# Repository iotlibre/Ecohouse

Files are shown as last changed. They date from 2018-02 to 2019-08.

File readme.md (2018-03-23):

# EcoHouse

Este kit de medida está pensado para tomar las medidas de consumo eléctrico de una vivienda o de un edificio con consumos inferiores a 10 KW. El sistema permite diferenciar varias zonas.

EcoHouse se puede instalar en el cuadro eléctrico principal o en cualquier otra parte  que nos permita tomar datos del consumo mediante pinzas (transformadores de intensidad). 

En el un edificio podemos tener tantos dispositivos como sean necesarios y el servidor EcoEficiencia los integrará en la misma instalación sin necesidad de configuraciones adicionales o cambios en el Firmware.

La comunicación se hace mediante Wifi por lo que no es necesario el cableado de datos al equipo solamente es necesario que esté dentro de la cobertura de la red WIFI del edificio. 

Para su uso no son necesarios conocimientos de informática aunque todos los desarrollos y el hardware están hechos bajo licencias libres lo que permite la modificación y mejora de las funcionalidades.

## Listado con las principales características
Las principales características de EcoBuilding son:
- 6 entradas para sensores de corriente con salida estandar de 50 mA o 1 Voltio
- Comunicación a Internet por WIFI local
- Configurable vía Web
- Display para mostrar el consumo instantáneo
- Alimentación a 220 voltios de corriente alterna
- Montaje en carril din
- Es posible configurar dos entradas analógicas adicionales pero en este caso el display permanecerá inoperativo
- La PCB integra un Arduino nano  con el ESP8266 12E
- Compatible con el [servidor de Open Energy Monitor](https://emoncms.org/)

## Montaje
El listado de componentes que has debido recibir es el siguientes:

- 1 PCB con los componentes de superficie ya montados
- 1 Carcasa para carril DIN
- 1 Tapa superior carcasa con display LCD 1602 y adaptador IIC/I2C
- 1 PCB Mesh building
- 1 Fuente de alimentación a 12 voltios
- 1 Arduino Nano
- 1 Integrado ESP8266 12E con el firmware mesh_building incluido
- 1 Convertidor DC-DC Step Down ajustable (salida 7,5V)
- 1 Regulador de tensión LM 1117
- 2 Conectores macho -hembra de 2.0mm para el ESP
- 2 Conectores macho hembra de 2.54mm para Arduino
- 2 Conectores macho hembra de 2.54mm para al display
- 9 Terminales de tornillo para PCB
- 2 Resistencias 10k 
- 3 Condensador 22uF
- 1 Condensador de 100nF
- 1 Diodo 1N4007

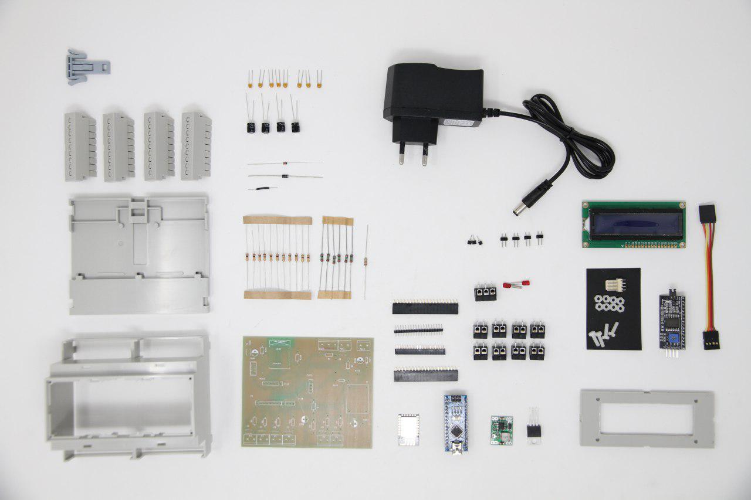
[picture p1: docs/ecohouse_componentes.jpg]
ecohouse_componentes


## Montaje
Partiendo de la PCB con los componentes de superficie soldar los componentes de menor a mayor tamaño por este orden:
- Resistencias
- Diodos
- Convertidor DC-DC Step Down ajustable (salida 7,5V)
- Conectores macho hembra de 2.0mm para el ESP
- Conectores macho hembra de 2.54mm para Arduino
- Conectores macho hembra de 2.54mm para al display
- Terminales de tornillo para PCB
- Condensador 22uF
- Condensador de 100nF
- Regulador de tensión LM 1117
 
Una vez esta completa la PCB insertar los integrados en sus posiciones
- Integrado ESP8266 12E
- Arduino Nano

Mirar la imagen para colocar los integrados de forma correcta, de otra maner no funcionarán y pueden sufrir daños
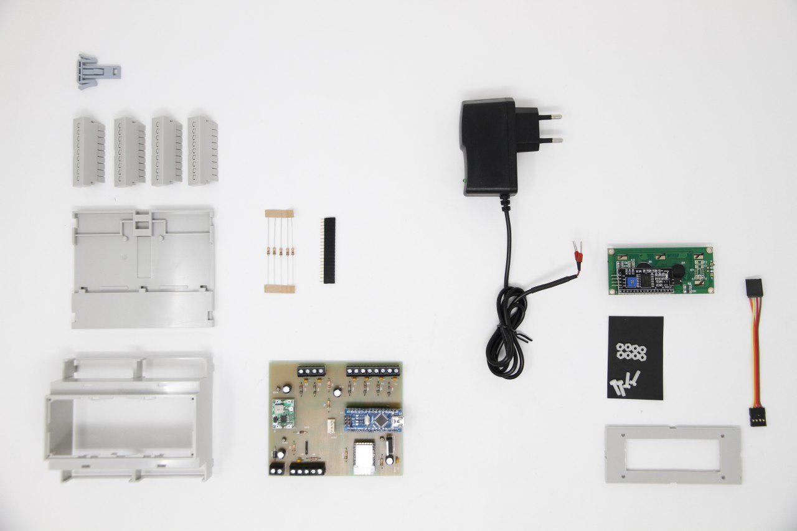
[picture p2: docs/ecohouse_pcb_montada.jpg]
ecohouse pcb montada


Por último conectar la tapa superior con el display a la PCB y montar la carcasa.

## Puesta a punto
La puesta a punto de libre_building consta de dos partes:
- El ajuste del voltaje de trabajo
- La configuración en la instalación

### El ajuste del voltaje de trabajo
El ajuste del voltaje de trabajo se hace para adaptar cualquier alimentación al voltaje de trabajo de EcoHouse que es 7,5 voltios.

La fuente de alimentación suministrada es de 12 voltios aunque el dispositivo funciona correctamente siempre que el voltaje de trabajo quede configurado entre 7 y 9 voltios.

Una vez conectada la  fuente de alimentación medir el voltaje en el punto (W103), situado al lado de  el Convertidor DC-DC (U1), y ajustarlo a 7,5 voltios con el potenciómetro que incorpora el convertidor. 

### La configuración en la instalación
En este punto se definen los parámetros del servidor de destino y la wifi local a la que va a estar conectado el dispositivo. Con este fin, la primera vez que se ponga en servicio el ESP y siempre que no encuentre la WIFI configurada, el ESP 8266 12E creará su propio punto de acceso, su propia red WIFI . Conectandose a cualquier dirección a través de este punto de acceso nos aparecerá la página de configuración del ESP. Tengase en cuenta que una  vez configurado el ESP y conectado a una red WIFI el router le asignará una única dirección IP a la que será necesario acceder para cambiar la configuración.

En caso de que se quiera actualizar el firmware del ESP a la última versión, este se puede encontrar en: [ecohouse-emonESP ](https://github.com/iotlibre/Ecohouse/tree/master/EmonESP)

### El firmware de Arduino
El firmware que que esta cargado por defecto en el arduino nano funciona correctamente sin embargo si quiere cambiar la configuración puedes encontrar la última actualización del firmware en este repositorio:[ecohouse-nano ](https://github.com/iotlibre/Ecohouse/tree/master/ecohouse-arduino_1)

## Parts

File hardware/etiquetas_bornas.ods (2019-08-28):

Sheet: Sheet1
CA | GND |  |  |  |  |  |  | 12V | GND
5V | 18B | GND
I1 | GND | I2 | GND | PR | GND
24 | GND | +30 | -30
GND | 18B | 5V | GND | CA |  | GND | 12V
GND | I1 | -15 | +15 | GND | I2 | -15 | +15
GND | PR | 24
GND | 18B | 5V | GND | CA |  | GND | 12V
GND | I1 | -15 | +15 | GND | I2 | -15 | +15
GND | PR | 24
GND | 18B | 5V | GND | CA |  | GND | 12V
P1+ | P1- | P2+ | P2- | P3+ | P3- | P4+ | P4-
P7+ | P7- | P8+ | P8-

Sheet: Para_imprimir
GND | 18B | 5V | GND | CA |  | GND | 12V | GND | 18B | 5V | GND | CA |  | GND | 12V
P1+ | P1- | P2+ | P2- | P3+ | P3- | P4+ | P4- | P1+ | P1- | P2+ | P2- | P3+ | P3- | P4+ | P4-
P7+ | P7- | P8+ | P8- |  |  |  |  | P7+ | P7- | P8+ | P8-
GND | 18B | 5V | GND | CA |  | GND | 12V | GND | 18B | 5V | GND | CA |  | GND | 12V
P1+ | P1- | P2+ | P2- | P3+ | P3- | P4+ | P4- | P1+ | P1- | P2+ | P2- | P3+ | P3- | P4+ | P4-
P7+ | P7- | P8+ | P8- |  |  |  |  | P7+ | P7- | P8+ | P8-
 | P7+ | P7- | P8+ | P8- |  | GND | 12V |  | P7+ | P7- | P8+ | P8- |  | GND | 12V
P1+ | P1- | P2+ | P2- | P3+ | P3- |  |  | P1+ | P1- | P2+ | P2- | P3+ | P3-
P4+ | P4- |  |  |  |  |  |  | P4+ | P4-
GND | 18B | 5V | GND | CA |  | GND | 12V | GND | 18B | 5V | GND | CA |  | GND | 12V
P1+ | P1- | P2+ | P2- | P3+ | P3- | P4+ | P4- | P1+ | P1- | P2+ | P2- | P3+ | P3- | P4+ | P4-
P7+ | P7- | P8+ | P8- |  |  |  |  | P7+ | P7- | P8+ | P8-
GND | 18B | 5V | GND | CA |  | GND | 12V | GND | 18B | 5V | GND | CA |  | GND | 12V
P1+ | P1- | P2+ | P2- | P3+ | P3- | P4+ | P4- | P1+ | P1- | P2+ | P2- | P3+ | P3- | P4+ | P4-
P7+ | P7- | P8+ | P8- |  |  |  |  | P7+ | P7- | P8+ | P8-
GND | 18B | 5V | GND | CA |  | GND | 12V | GND | 18B | 5V | GND | CA |  | GND | 12V
P1+ | P1- | P2+ | P2- | P3+ | P3- | P4+ | P4- | P1+ | P1- | P2+ | P2- | P3+ | P3- | P4+ | P4-
P7+ | P7- | P8+ | P8- |  |  |  |  | P7+ | P7- | P8+ | P8-

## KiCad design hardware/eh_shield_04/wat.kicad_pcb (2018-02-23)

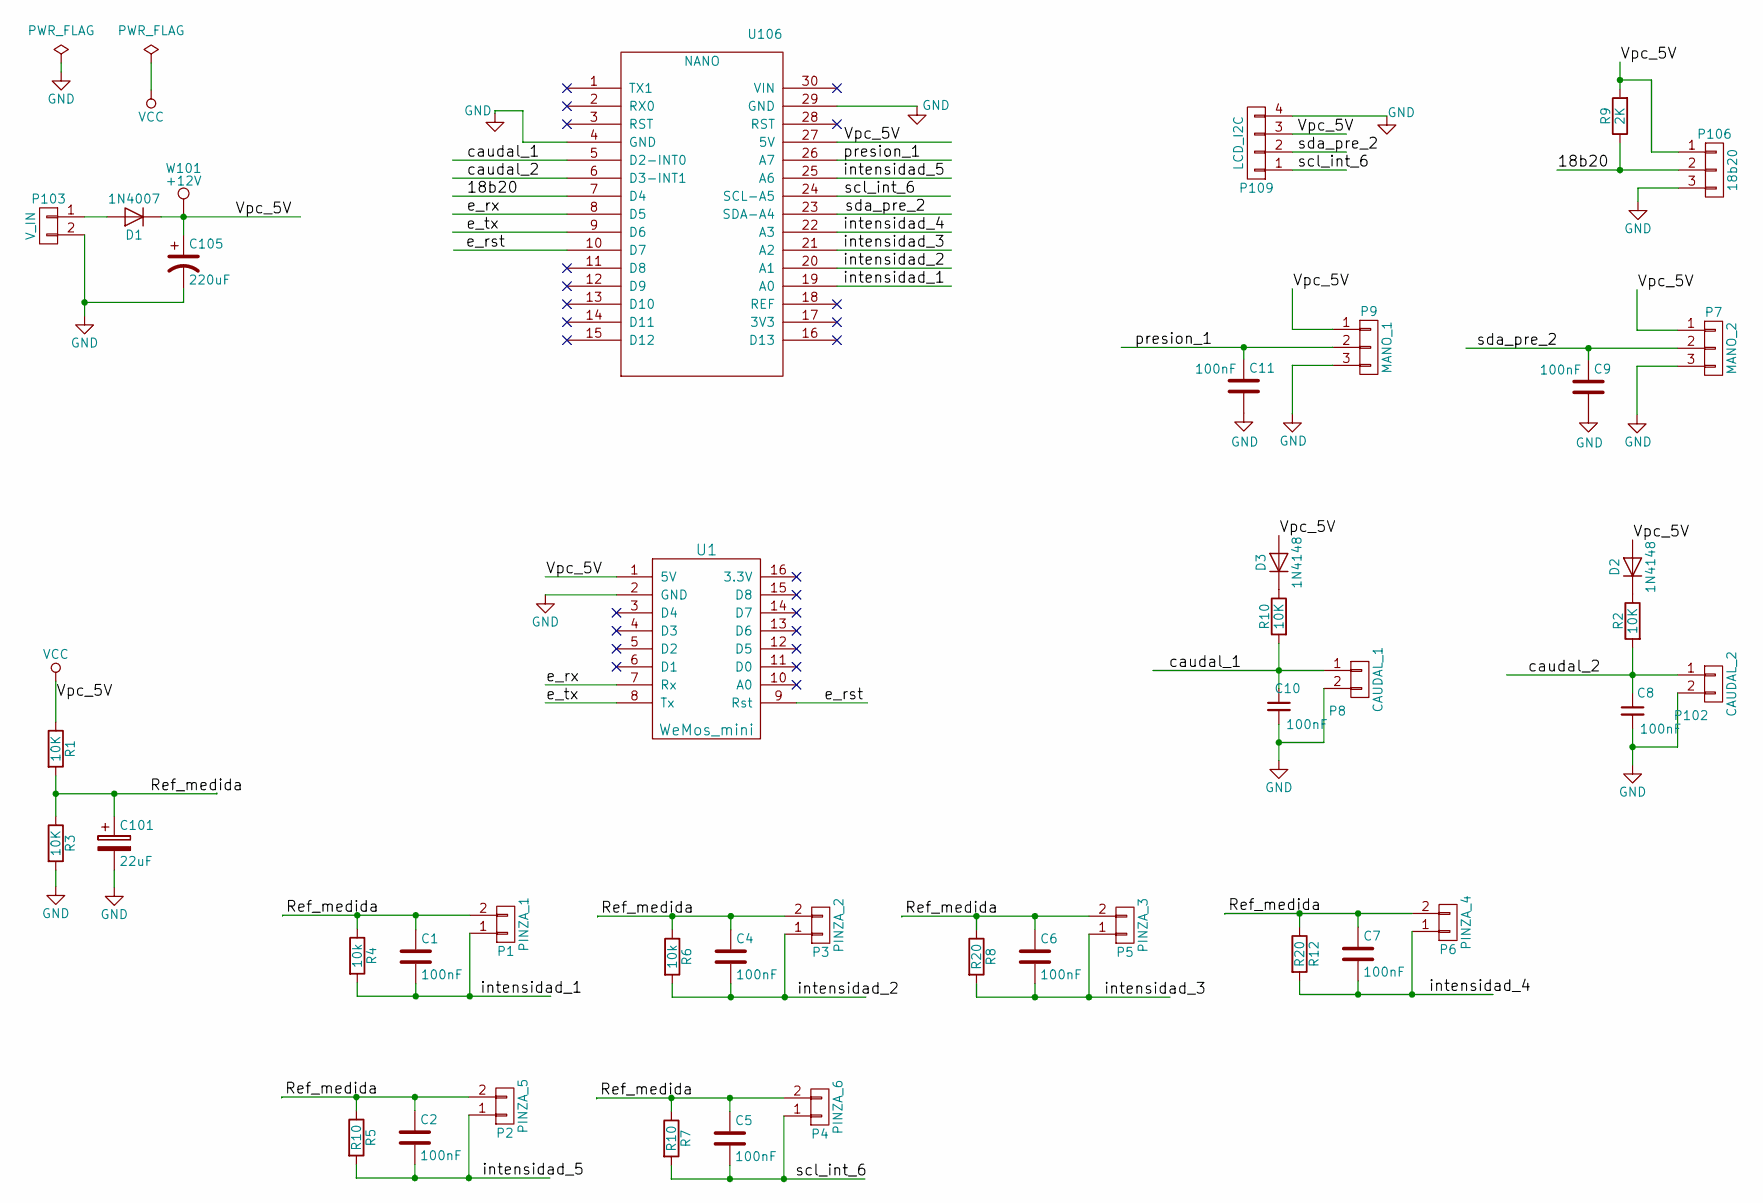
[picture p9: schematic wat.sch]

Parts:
C1, C2, C4, C5, C6, C7, C8, C9, C10, C11: 100nF; C_Disc_D5.0mm_W2.5mm_P5.00mm
C101: 22uF; CP_Radial_D5.0mm_P2.00mm
C105: 220uF; CP_Radial_D5.0mm_P2.00mm
D1: 1N4007; Diode_DO-35_SOD27_Horizontal_RM10
D2, D3: 1N4148; D_A-405_P7.62mm_Horizontal
P1: PINZA_1; bornier2
P2: PINZA_5; bornier2
P3: PINZA_2; bornier2
P4: PINZA_6; bornier2
P5: PINZA_3; bornier2
P6: PINZA_4; bornier2
P7: MANO_2; bornier3
P8: CAUDAL_1; bornier2
P9: MANO_1; bornier3
P102: CAUDAL_2; bornier2
P103: V_IN; bornier2
P106: 18b20; bornier3
P109: LCD_I2C; Pin_Header_Straight_1x04
R1, R2, R3, R10: 10K; Resistor_Horizontal_RM10mm
R4, R6: 10k; Resistor_Horizontal_RM10mm
R5, R7: R10; Resistor_Horizontal_RM10mm
R8, R12: R20; Resistor_Horizontal_RM10mm
R9: 2K; Resistor_Horizontal_RM10mm
U1: WeMos_mini; D1_mini_board_direct
U106: NANO; arduino_nano
W101: +12V; SolderWirePad_single_0-8mmDrill

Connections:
/18b20: P106.2, R9.1, U106.7 (D4)
/Ref_medida: C1.1, C2.1, C4.1, C5.1, C6.1, C7.1, C101.1, P1.2, P2.2, P3.2, P4.2, P5.2, P6.2, R1.2, R3.1, R4.1, R5.1, R6.1, R7.1, R8.1, R12.1
/caudal_1: C10.1, P8.1, R10.2, U106.5 (D2-INT0)
/caudal_2: C8.1, P102.1, R2.2, U106.6 (D3-INT1)
/e_rst: U1.9 (Rst), U106.10 (D7)
/e_rx: U1.7 (Rx), U106.8 (D5)
/e_tx: U1.8 (Tx), U106.9 (D6)
/intensidad_1: C1.2, P1.1, R4.2, U106.19 (A0)
/intensidad_2: C4.2, P3.1, R6.2, U106.20 (A1)
/intensidad_3: C6.2, P5.1, R8.2, U106.21 (A2)
/intensidad_4: C7.2, P6.1, R12.2, U106.22 (A3)
/intensidad_5: C2.2, P2.1, R5.2, U106.25 (A6)
/presion_1: C11.1, P9.2, U106.26 (A7)
/scl_int_6: C5.2, P4.1, P109.1, R7.2, U106.24 (SCL-A5)
/sda_pre_2: C9.1, P7.2, P109.2, U106.23 (SDA-A4)
GND: C8.2, C9.2, C10.2, C11.2, C101.2, C105.2, P7.3, P8.2, P9.3, P102.2, P103.2, P106.3, P109.4, R3.2, U1.2 (GND), U106.4 (GND), U106.29 (GND)
unnamed: D1.2 (A), P103.1
unnamed: D2.1 (K), R2.1
unnamed: D3.1 (K), R10.1
VCC: C105.1, D1.1 (K), D2.2 (A), D3.2 (A), P7.1, P9.1, P106.1, P109.3, R1.1, R9.2, U1.1 (5V), U106.27 (5V), W101.1

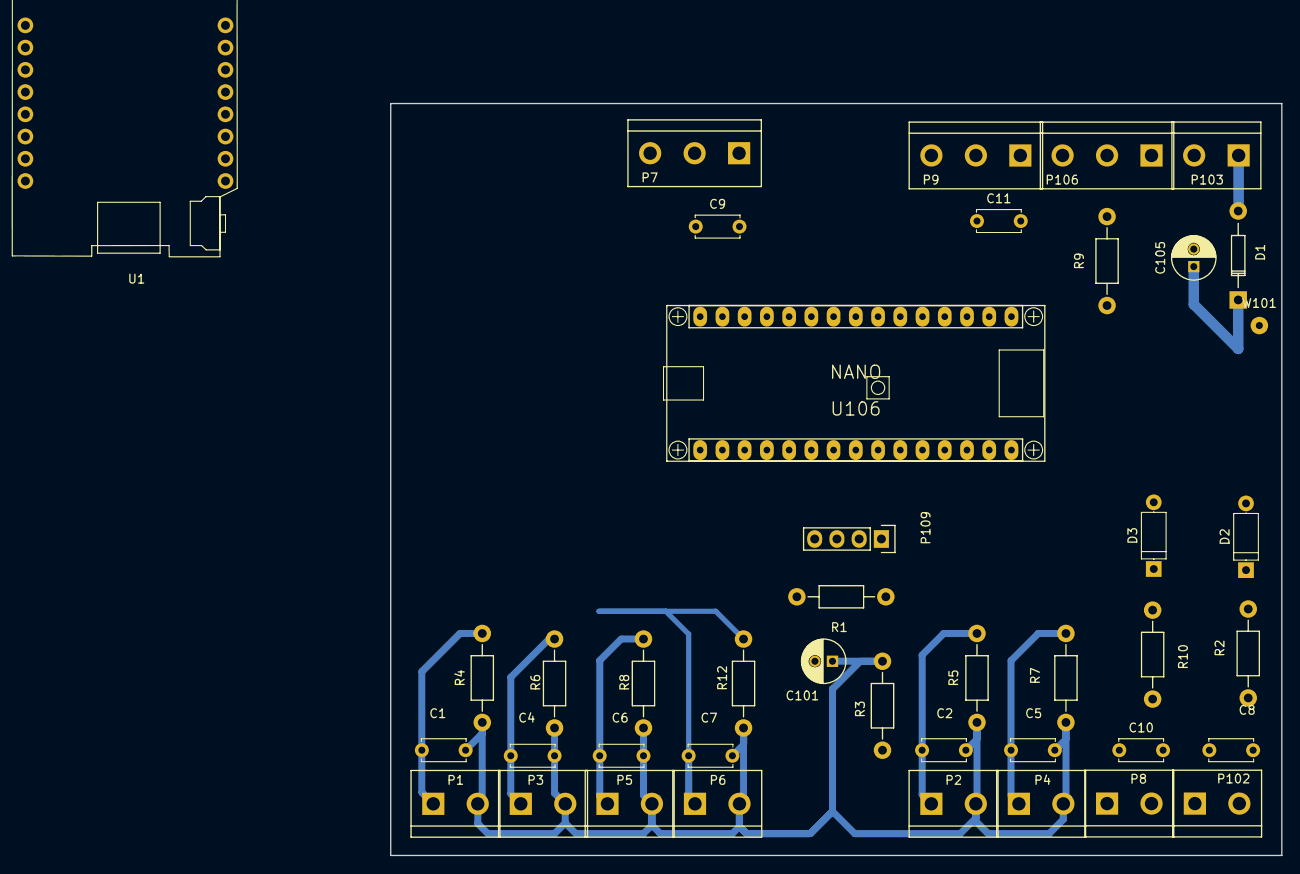
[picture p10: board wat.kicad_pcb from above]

Board: 2 copper layers, 101.8 x 85.9 mm, 42 parts (0 on the bottom side), 20 nets.

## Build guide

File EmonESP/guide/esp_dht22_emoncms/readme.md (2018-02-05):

# ESP DHT22 to Emoncms Example

An example made using the [Adafruit Huzzah](https://www.adafruit.com/product/2471) board with ESP-12 module and the DHT22 temperature humidity sensor.

This code example, when loaded onto the ESP will continuously upload temperature and humidity data onto [emoncms.org](https://emoncms.org)

[CP2102 USB to UART adapter](https://shop.openenergymonitor.com/programmers) was used as power supply and to program the ESP. 
PlatformIO or Arduino IDE can be used to compile and upload code. See [PlatformIO compile and upload guide](https://guide.openenergymonitor.org/technical/compiling)

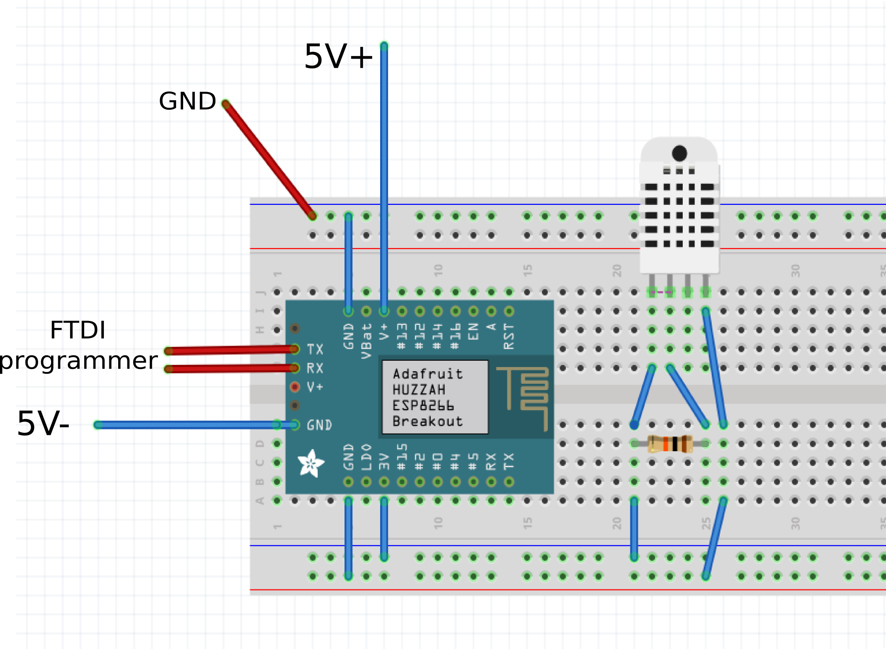
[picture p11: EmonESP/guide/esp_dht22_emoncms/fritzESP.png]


Thanks to @myrddinmuse for puting together this example.

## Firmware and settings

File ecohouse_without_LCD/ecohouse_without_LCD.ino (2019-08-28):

#define DEBUG 0

#define BPS 115200 //Velocidad de las comunicaciones

#include <SoftwareSerial.h>
#define RXPIN 6
#define TXPIN 5
SoftwareSerial wifiSerialInit (RXPIN,TXPIN);

#include "power_sensor.h"

uint32_t t_last_tx=0;
uint32_t t_last_lcd=0;

void setup(void)

  {     
     Serial.begin(BPS);
     wifiSerialInit.begin(BPS);
  }

void loop(void)
  {
    uint32_t current_time= millis();
    
    if ((current_time - t_last_tx) > 40000)
      {      
        Serial.print(F("******Print WIFI - sgs: "));
        t_last_tx = current_time;
        Serial.println(millis() / 1000);
        //buildTemperatureMessage(0);
        buildPowerMessage(0);
      }

    if ((current_time - t_last_lcd) > 20000)
      {     
        Serial.print(F("******Print LCD - sgs: "));
        t_last_lcd = current_time;
        Serial.println(millis() / 1000);
        //buildTemperatureMessage(1);
        buildPowerMessage(1);
      }

  }
  

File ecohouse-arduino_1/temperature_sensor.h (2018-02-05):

#ifndef temperature_sensor_h
#define temperature_sensor_h


// *******************************************************
// ******** CONFIGURACION SENSORES DE TEMPERATURA ********
// *******************************************************

// #define ONE_WIRE_BUS 6 // arduino uno
// #define ONE_WIRE_BUS 4 // arduino nano
#define ONE_WIRE_BUS 19 // pump A5 pin 28

// Lower resolution
#define TEMPERATURE_PRECISION 9

//#define POSITION_1  {0x28,0xFF,0xFD,0x36,0x84,0x16,0x04,0x98}
//#define POSITION_1  {0x28,0xA3,0x77,0x02,0x08,0x00,0x00,0x05}
#define POSITION_1  {0x28,0xff,0xb6,0x39,0x84,0x16,0x04,0x9b}
#define NAME_SENSOR_1 "Temp_Out" 
#define POSITION_2  {0x28,0x7B,0x6B,0x02,0x08,0x00,0x00,0x3D}
#define NAME_SENSOR_2 "Temp_In" 
#define POSITION_3  {0x28,0x53,0x8E,0x01,0x08,0x00,0x00,0xAA}
#define NAME_SENSOR_3 "Temp_Amb"
#define POSITION_4  {0x28,0xFF,0x86,0x40,0x70,0x16,0x05,0x69}
#define NAME_SENSOR_4 "Tra Planta 3" 
#define POSITION_5  {0xEE,0xEE,0xEE,0xEE,0xEE,0xEE,0xEE,0xEE}
#define NAME_SENSOR_5 " SENSOR POSITION" 
#define POSITION_6  {0xEE,0xEE,0xEE,0xEE,0xEE,0xEE,0xEE,0xEE}
#define NAME_SENSOR_6 " SENSOR POSITIONL" 
#define POSITION_7  {0xEE,0xEE,0xEE,0xEE,0xEE,0xEE,0xEE,0xEE}
#define NAME_SENSOR_7 " SENSOR POSITION" 
#define POSITION_8  {0xEE,0xEE,0xEE,0xEE,0xEE,0xEE,0xEE,0xEE}
#define NAME_SENSOR_8 " SENSOR POSITION" 
#define POSITION_9  {0xEE,0xEE,0xEE,0xEE,0xEE,0xEE,0xEE,0xEE}
#define NAME_SENSOR_9 " SENSOR POSITION"
#define POSITION_10  {0xEE,0xEE,0xEE,0xEE,0xEE,0xEE,0xEE,0xEE}
#define NAME_SENSOR_10 " SENSOR POSITION"
#define POSITION_11  {0xEE,0xEE,0xEE,0xEE,0xEE,0xEE,0xEE,0xEE}
#define NAME_SENSOR_11 " SENSOR POSITION" 
#define POSITION_12  {0xEE,0xEE,0xEE,0xEE,0xEE,0xEE,0xEE,0xEE}
#define NAME_SENSOR_12 " SENSOR POSITION" 


// *******************************************************

#include <OneWire.h>
#include <DallasTemperature.h>

void buildTemperatureMessage(uint8_t);
String printName(DeviceAddress deviceAddress);
bool compareAddress(DeviceAddress deviceAddress_c_1, DeviceAddress deviceAddress_c_2);
void printResoltion(DeviceAddress deviceAddressPr);
String printAddress(DeviceAddress deviceAddressPa);
void temperatureSensorsBegin();


DeviceAddress tempDeviceAddress;
OneWire oneWire(ONE_WIRE_BUS);
DallasTemperature sensors_m(&oneWire);


 //DeviceAddress
uint8_t deviceAddress_1[]=POSITION_1;
uint8_t deviceAddress_2[]=POSITION_2;
uint8_t deviceAddress_3[]=POSITION_3;
uint8_t deviceAddress_4[]=POSITION_4;
uint8_t deviceAddress_5[]=POSITION_5;
uint8_t deviceAddress_6[]=POSITION_6;
uint8_t deviceAddress_7[]=POSITION_7;
uint8_t deviceAddress_8[]=POSITION_8;
uint8_t deviceAddress_9[]=POSITION_9;
uint8_t deviceAddress_10[]=POSITION_10;
uint8_t deviceAddress_11[]=POSITION_11;
uint8_t deviceAddress_12[]=POSITION_12;


String temperatureString = (""); 
uint8_t numberOfDevices=0;


void buildTemperatureMessage(uint8_t output) {
  
    if (DEBUG) Serial.println(F("********buildTemperatureMessage()"));
    numberOfDevices = sensors_m.getDeviceCount();
    if (DEBUG) Serial.print(F("numberOfDevices = "));
    if (DEBUG) Serial.println(numberOfDevices);
    sensors_m.requestTemperatures();

    
    
    for(int i=0;i<numberOfDevices; i++)
        {
           if(sensors_m.getAddress(tempDeviceAddress, i))
           {
             if (DEBUG) Serial.print(F("****device number= "));
             if (DEBUG) Serial.println(i);
             float tempC = sensors_m.getTempC(tempDeviceAddress);
             String value_18 = String(tempC,1);
             String name_18 = printName(tempDeviceAddress);
             if (DEBUG) Serial.println(name_18 + ":" + value_18);             

             if (output==0) 
                 {
                      // lcd.clear();
                      // lcd.setCursor(0, 0); lcd.print(name_18);
                      // lcd.setCursor(0, 1);lcd.print(value_18);
                      // wifiBasic.enviarPost(name_18, value_18);
		                  Serial.print("sensor_name:" + name_18);
                      Serial.println(",sensor_value:" + value_18);
                  }


             if (output==1) 
                 {  
                     // lcd.clear();
                     // lcd.setCursor(0, 0); lcd.print(name_18);
                     // lcd.setCursor(0, 1);lcd.print(value_18);
                     // delay(4000);
                     Serial.println(name_18 + ": " + value_18);
                  }

             // if (output==2) wifiBasic.enviarPost(name_18, value_18);
             

             
           }
        }
}


String printName(DeviceAddress deviceAddress)
{
  
  String temp_sensor_name;

  // Incluye el nombre del sensor
  if     (compareAddress(deviceAddress,deviceAddress_1))  {temp_sensor_name = F((NAME_SENSOR_1));}
  else if(compareAddress(deviceAddress,deviceAddress_2))  {temp_sensor_name = F((NAME_SENSOR_2));} 
  else if(compareAddress(deviceAddress,deviceAddress_3))  {temp_sensor_name = F((NAME_SENSOR_3));} 
  else if(compareAddress(deviceAddress,deviceAddress_4))  {temp_sensor_name = F((NAME_SENSOR_4));} 
  else if(compareAddress(deviceAddress,deviceAddress_5))  {temp_sensor_name = F((NAME_SENSOR_5));}  
  else if(compareAddress(deviceAddress,deviceAddress_6))  {temp_sensor_name = F((NAME_SENSOR_6));} 
  else if(compareAddress(deviceAddress,deviceAddress_7))  {temp_sensor_name = F((NAME_SENSOR_7));}  
  else if(compareAddress(deviceAddress,deviceAddress_8))  {temp_sensor_name = F((NAME_SENSOR_8));}  
  else if(compareAddress(deviceAddress,deviceAddress_9))  {temp_sensor_name = F((NAME_SENSOR_9));} 
  else if(compareAddress(deviceAddress,deviceAddress_10)) {temp_sensor_name = F((NAME_SENSOR_10));} 
  else if(compareAddress(deviceAddress,deviceAddress_11)) {temp_sensor_name = F((NAME_SENSOR_11));} 
  else if(compareAddress(deviceAddress,deviceAddress_12)) {temp_sensor_name = F((NAME_SENSOR_12));}   

  else temp_sensor_name = printAddress(deviceAddress);

 return temp_sensor_name;
 
}

  

bool compareAddress(DeviceAddress deviceAddress_c_1, DeviceAddress deviceAddress_c_2)
  {
    for(int i=0;i<7; i++)
      {
        if (deviceAddress_c_1[i] != deviceAddress_c_2[i]){return false;}
      }
    return true;
  }

void printResoltion(DeviceAddress deviceAddressPr)
{
  temperatureString += (sensors_m.getResolution(deviceAddressPr), DEC); 
}



String printAddress(DeviceAddress deviceAddressPa)
{ 
  String string_temp_r="";
  for (uint8_t i = 0; i < 8; i++)
  {
    if (deviceAddressPa[i] < 16) string_temp_r += ("0");
    uint8_t temp= (deviceAddressPa[i]);
    String stringTemp =  String(temp, HEX);  
    string_temp_r = string_temp_r +stringTemp;
  }
  return string_temp_r;
}

void temperatureSensorsBegin() {sensors_m.begin();}



#endif

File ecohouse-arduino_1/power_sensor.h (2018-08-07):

#ifndef power_sensor_h
#define power_sensor_h

// *******************************************************
// ******** CONFIGURACION SENSORES DE POTENCIA    ********
// *******************************************************

// 97.6  

#define NUMBER_OF_PWR_SENSORS 3

#define MAME_PWR_1 "Pinza_1"
#define ENTER_1 A0
#define CURRENT_CONST_1 195

#define MAME_PWR_2 "Pinza_2"
#define ENTER_2 A1
#define CURRENT_CONST_2 195

#define MAME_PWR_3 "Pinza_3"
#define ENTER_3 A2
#define CURRENT_CONST_3 195

#define MAME_PWR_4 "Pinza_4"
#define ENTER_4 A3
#define CURRENT_CONST_4 195

#define MAME_PWR_5 "Pinza_7"
#define ENTER_5 A6
#define CURRENT_CONST_5 195

#define MAME_PWR_6 "Pinza_8"
#define ENTER_6 A7
#define CURRENT_CONST_6 195


// *******************************************************

#include "EmonLib.h"                   // Include Emon Library
EnergyMonitor emon1;

// variable declaration

String name_pwr[]=
  {
    MAME_PWR_1,
    MAME_PWR_2,
    MAME_PWR_3,
    MAME_PWR_4,
    MAME_PWR_5,
    MAME_PWR_6
  };

int enter_pin[]=
  {
    ENTER_1,
    ENTER_2,
    ENTER_3,
    ENTER_4,
    ENTER_5,
    ENTER_6


    
  };

float current_const[]=
  {
    CURRENT_CONST_1,
    CURRENT_CONST_2,
    CURRENT_CONST_3,
    CURRENT_CONST_4,
    CURRENT_CONST_5,
    CURRENT_CONST_6
  }; 

// Function Prototypes
void buildPowerMessage(uint8_t);


void buildPowerMessage(uint8_t output)
  {
    for (uint8_t i=0; i < NUMBER_OF_PWR_SENSORS; i++)
      {      
        emon1.current(enter_pin[i],current_const[i]);      // Current: input pin, calibration.

        for (uint8_t i=0; i<9; i++)
          {
            double Irms = emon1.calcIrms(1480);  // Calculate Irms only
          }
        
        double Irms = emon1.calcIrms(1480);
        double Pwr=(Irms*230.0); 
      
        String value_pwr = String(Pwr,2);    
        if (output==0) 
          {
            Serial.println("wifiSerialInit.println");
            Serial.println (name_pwr[i] + ":" + value_pwr);

            lcd.clear();
            lcd.setCursor(0, 0); lcd.print(name_pwr[i]+"  ->");
            lcd.setCursor(0, 1);lcd.print(value_pwr + " W");

            wifiSerialInit.println (name_pwr[i] + ":" + value_pwr);
          }
        if (output==1) 
          {
            Serial.println("wifiSerialInit.println");
            Serial.println (name_pwr[i] + ":" + value_pwr);
            
            lcd.clear();
            lcd.setCursor(0, 0); lcd.print(name_pwr[i]);
            lcd.setCursor(0, 1);lcd.print(value_pwr + " W");

          }
      }
  }

#endif

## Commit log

2018-02-05 comit de inicio de ecohouse
    [wat.kicad_pcb, wat.sch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]
2018-02-08 cambios hacia nueva version de PCB
    [wat.kicad_pcb, wat.sch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]
2018-02-09 cambios hacia PCB con presion
    [wat.sch]
2018-02-16 incluir fichero de mejoras
2018-02-23 hw wemos incluido
    [wat.kicad_pcb, wat.sch]
2018-09-06 I2C direction for display
2019-08-28 sensibilidad en emonlib y eliminada la medida de temperatura
    [etiquetas_bornas.ods]
2019-09-20 plan de contingencia Adecuara
